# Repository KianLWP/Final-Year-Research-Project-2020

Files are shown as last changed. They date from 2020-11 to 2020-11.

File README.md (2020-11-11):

# Final-Year-Research-Project-2020
Repository for files and code used for my final year research project 2020: Inverted Pendulum Robot using IMU and Optical Flow as Feedback.    

A playlist with video demonstrations of the robot balancing can be found here:  
https://www.youtube.com/playlist?list=PL7QYRT00v9nzqrD0AZgUXMDRnrYgOC2eC

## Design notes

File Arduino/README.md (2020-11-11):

This directory contains the Arduino code used.    

The libraries used are Jeff Rowberg's MPU6050 library for Arduino, Pololu's VL53L1X library for Arduino and Bitcraze's Arduino driver for PMW3901 optical flow sensor.     
The links for their GitHubs are:      
https://github.com/jrowberg/i2cdevlib/tree/master/Arduino/MPU6050       
https://github.com/pololu/vl53l1x-arduino    
https://github.com/bitcraze/Bitcraze_PMW3901

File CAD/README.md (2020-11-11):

The CAD models for both the physical system and the electronic circuit can be found here.

Robot Assembly:

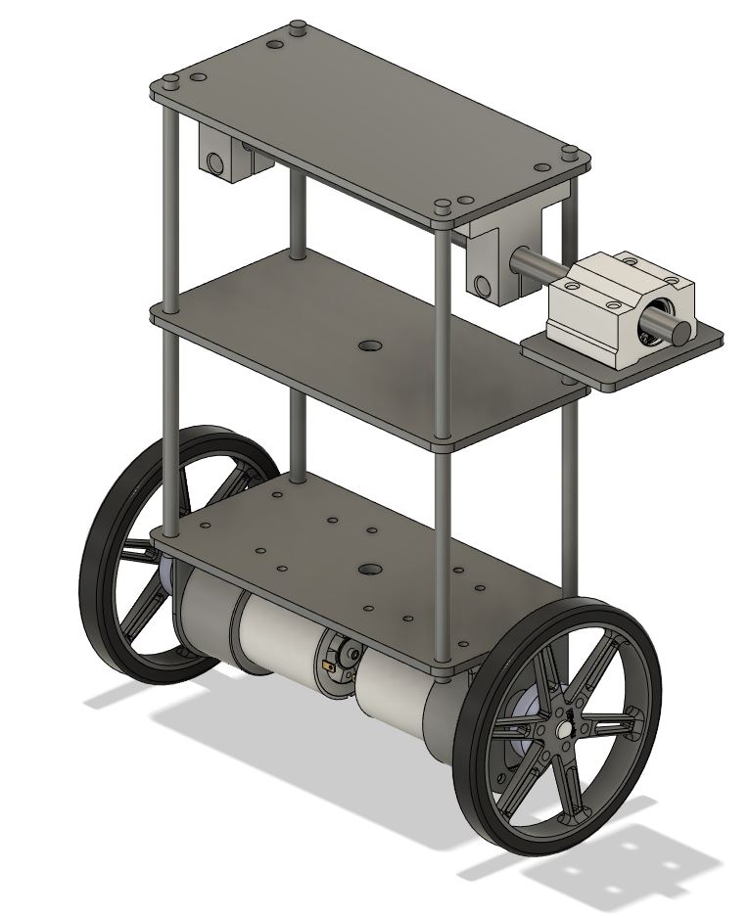
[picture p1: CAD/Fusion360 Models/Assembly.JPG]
Assembly


Circuit Design:

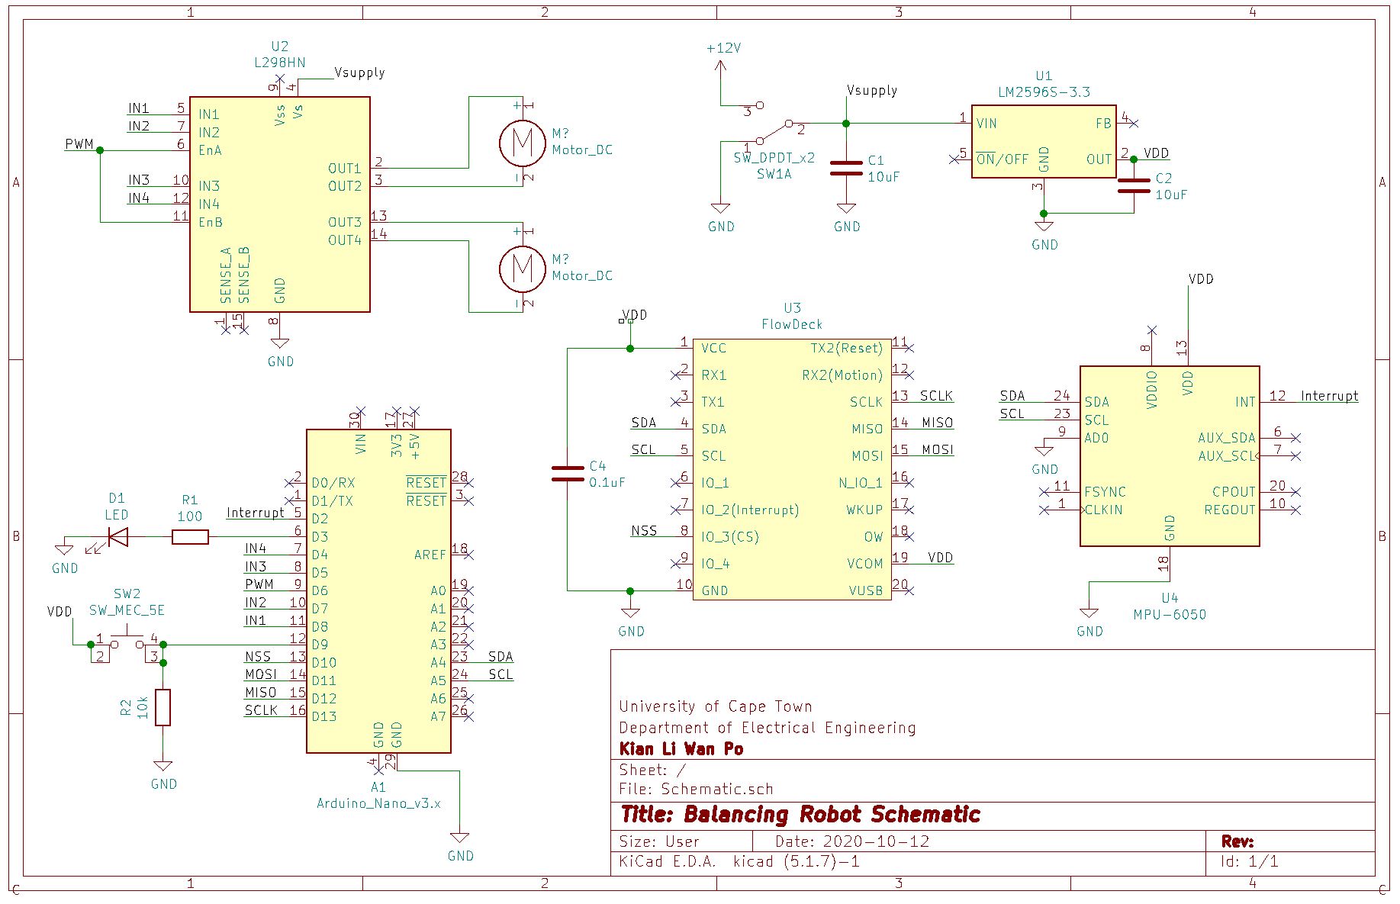
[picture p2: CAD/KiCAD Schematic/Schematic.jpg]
Schematic


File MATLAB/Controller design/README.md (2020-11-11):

Data and code when designing controllers for the two wheel balancing robot

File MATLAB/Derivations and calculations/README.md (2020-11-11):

Parameter calcualtion for the robot as well as a complete MATLAB live script for calculating the equations of motion, state-space model and calculating estimated required motor torque.   

The scripts used to calculated the linearized and unlinearized equations of motion are included.

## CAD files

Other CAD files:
CAD/Fusion360 Models/37 mm DC Geared Motor Mounting Bracket.f3d
CAD/Fusion360 Models/8mm rod.f3d
CAD/Fusion360 Models/Adjusted DC motor.f3d
CAD/Fusion360 Models/Gimballed Platform Assembly.f3z
CAD/Fusion360 Models/M5x160mm support rod.f3d
CAD/Fusion360 Models/Platform_ bottom.f3d
CAD/Fusion360 Models/Platform_ general.f3d
CAD/Fusion360 Models/Platform_ gimbal.f3d
CAD/Fusion360 Models/Platform_ middle.f3d
CAD/Fusion360 Models/Platform_ top.f3d
CAD/Fusion360 Models/Robot Assembly.f3z
CAD/Fusion360 Models/SCS8UU Block, Linear Bearing, 8mm Shaft.f3d
CAD/Fusion360 Models/Wheel Assembly.f3z
CAD/Fusion360 Models/pololu-universal-aluminum-mounting-hub-for-6mm-shaft-4-40-holes.f3d
CAD/Fusion360 Models/pololu-wheel-80x10mm-black.f3d
CAD/Fusion360 Models/sk8_rod_holder_v2.f3d

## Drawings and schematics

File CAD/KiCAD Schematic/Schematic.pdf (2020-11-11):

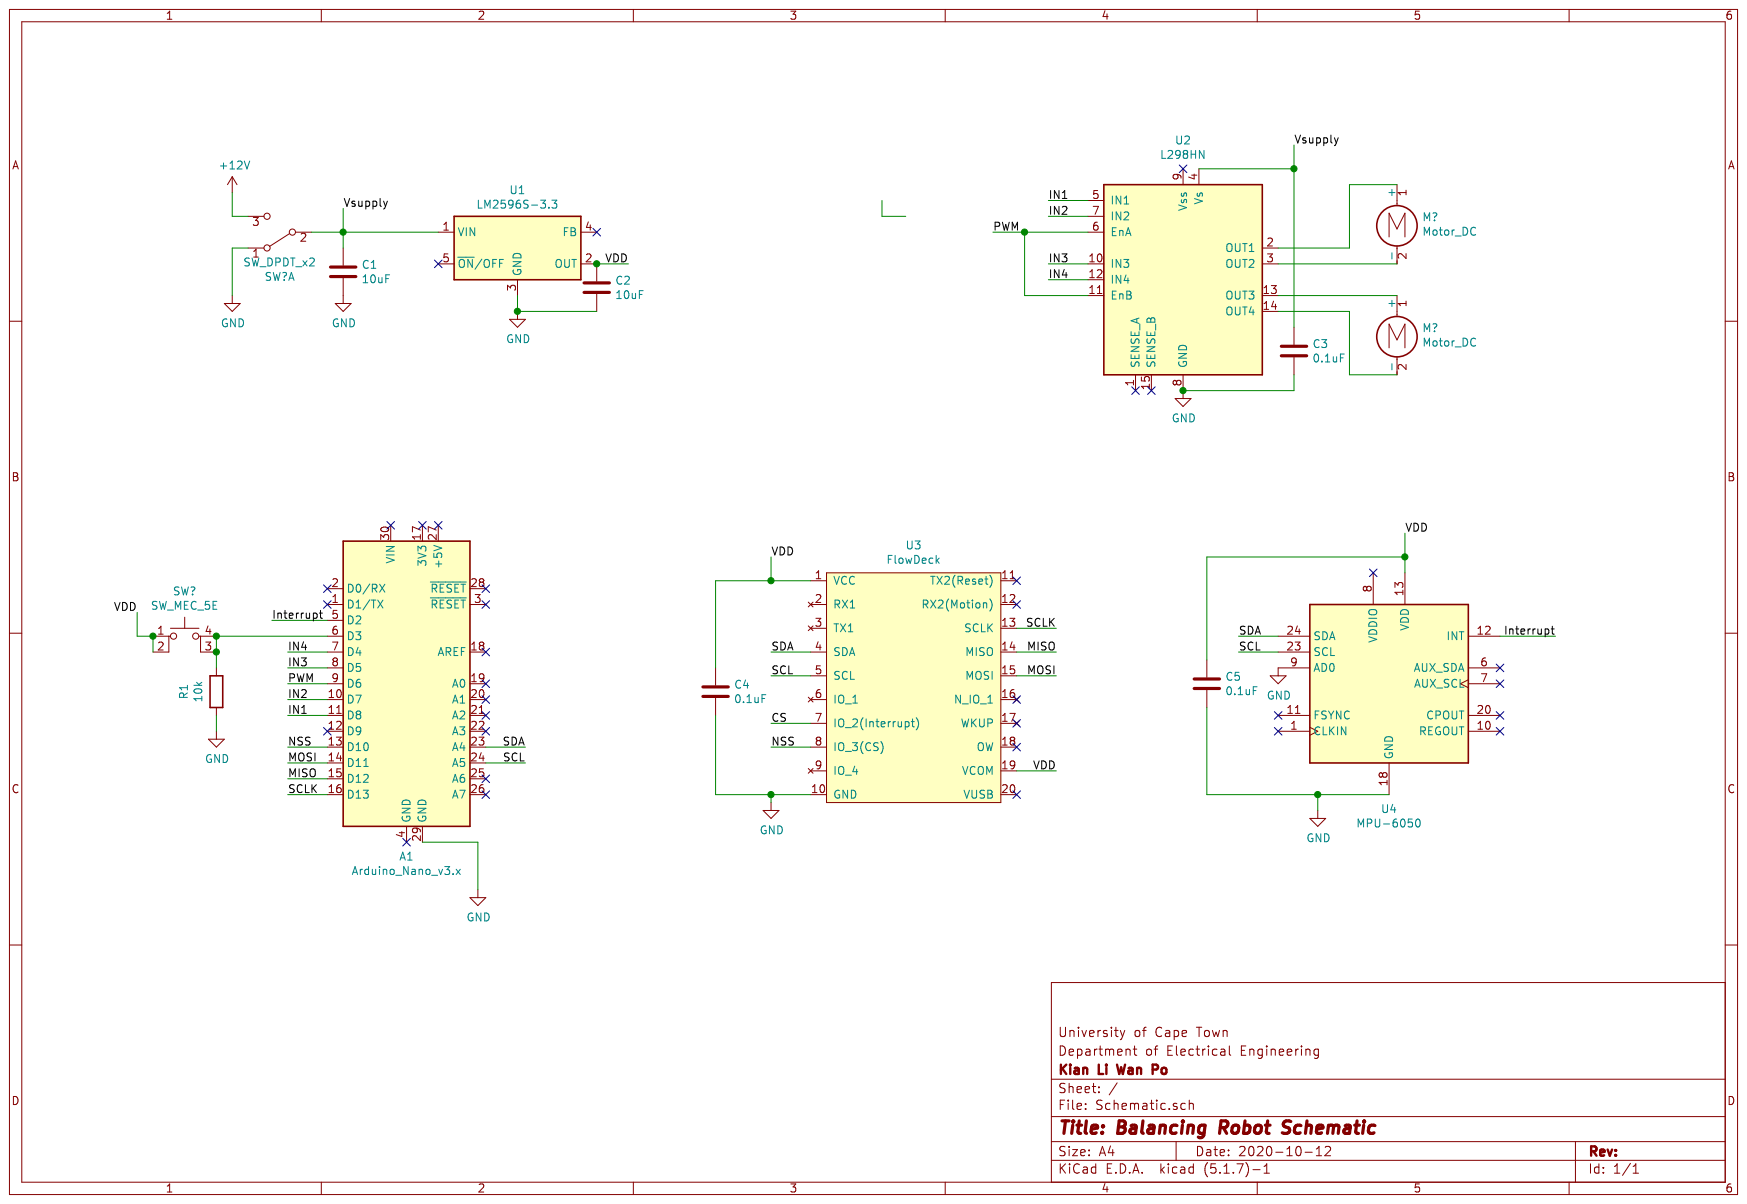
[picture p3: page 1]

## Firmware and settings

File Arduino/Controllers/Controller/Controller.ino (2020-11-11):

#include <Wire.h>
#include <VL53L1X.h>
#include "Bitcraze_PMW3901.h"
#include "MPU6050_6Axis_MotionApps20.h"


// ================================================================
// ===                        VARIABLES                         ===
// ================================================================

MPU6050 mpu;

//***************DMP VARIABLES*******************

// MPU control/status vars
bool dmpReady = false;  // set true if DMP init was successful
uint8_t mpuIntStatus;   // holds actual interrupt status byte from MPU
uint8_t devStatus;      // return status after each device operation (0 = success, !0 = error)
uint16_t packetSize;    // expected DMP packet size (default is 42 bytes)
uint16_t fifoCount;     // count of all bytes currently in FIFO
uint8_t fifoBuffer[64]; // FIFO storage buffer

// orientation/motion vars
Quaternion q;           // [w, x, y, z]         quaternion container
VectorFloat gravity;    // [x, y, z]            gravity vector
float euler[3];         // [psi, theta, phi]    Euler angle container
float ypr[3];           // [yaw, pitch, roll]   yaw/pitch/roll container and gravity vector

//***************VARIABLES*******************
// Program State
int ps = 0; //everytime push button is pressed or function is completed it is incremented
int btnPress = 0; 
//Loop variable
int c = 0;

//**************CONTROLLER GAINS******************

//float K1 = 0, K2 = 0, K3 = 0, K4 = 0;

//Ziegler Nichols
//Finding Ultimate gain and time
//float Kp = 150, Ki = 0, Kd = 0; //set gains to 0 and increase Kp until neutrally stable

//Ultimate Variables
float Ku = 150, Tu = 0.2168; //Found using Ziegler Nichols tuning method

      
//Gain Table

//Classic
// float Kp = Ku/2, Ki = 0, Kd = 0; //P
// float Kp = Ku/2.2, Ki = 1.2*Kp/Tu, Kd = 0; //PI
//float Kp = Ku*0.6, Ki = 2*Kp/Tu, Kd = Kp*Tu/8; //PID

//overshoot
//float Kp = 0.2*Ku;  //No overshoot
float Kp = 0.33*Ku; //Some overshoot
float Ki = 2*Kp/Tu, Kd = Kp*Tu/3; 

//Pessen Integral Rule
//float Kp = 0.7*Ku, Ki = 2.5*Kp/Tu, Kd = 0.15*Kp/Tu;


//old gains
//float Ku = 110, Tu = 0.22296; For gimbal //Original 70, 0.21964
//float Ku = 150, Tu = 0.5;
//float Ku = 100, Tu = 0.22694;

//
float errTot = 0, errPrev = 0;
//Time
unsigned long dt = 0, t0 = 0, t1 = 0; //time variable
//output  
const float v_min = 3.5;
const float v_max = 10.5;
float v_out;
int PWM_out;


//***************PINS**********************
#define INTERRUPT_PIN 2  // used for the DMP
#define LED 3   // LED pin
#define BTN 9 // switch button pin
//Left motor pins. 
//const int L_PWM = 9; 
#define L_IN1 8
#define L_IN2 7
//Right motor pins
#define R_PWM 6 //Using same PWM pin for consistency
#define R_IN1 5 
#define R_IN2 4

//**********PROGRAM SETTINGS**************
#define CALIBRATE_IMU;//comment to skip IMU calibration and use pre-calibrated offsets
//#define ZN_TUNING; //uncomment for Ziegler Nichols Tuning

void setup() {
  setupIMU();
  // Setup GPIO
  pinMode(LED, OUTPUT);
  pinMode(BTN, INPUT);

  //Motor setup
  pinMode(R_PWM, OUTPUT);
  pinMode(L_IN1, OUTPUT);
  pinMode(L_IN2, OUTPUT);
  pinMode(R_IN1, OUTPUT);
  pinMode(R_IN2, OUTPUT);

  Serial.println("Setup complete, awaiting user input");
  Serial.println("-----------------------------------");
  
  #ifdef ZN_TUNING
    Kp = 5;
    Ki = 0;
    Kd = 0;
    Serial.println("Ziegler Nichols Tuning");
  #endif

  Serial.print("Used gains: Kp=");
  Serial.print(Kp);
  Serial.print("  Ki=");
  Serial.print(Ki);
  Serial.print("  Kd=");
  Serial.println(Kd);
  Serial.println("-----------------------------------");
  
}

void loop() {
  ps = ps%5;  //ensures program state is from 0-3, including both 0 and 3
  switch (ps){
  case 1:
    initializeDMP();
    Serial.println("Ready to balance. Press button to start");
    Serial.println("---------------------------------------");
    ps++;
    break;
  case 2:
    c++;
    //do nothing, awaiting further user input
    digitalWrite(LED, (c/5000 % 2)); //blinks letting user know robot is ready
    break;
  case 3:
    if (mpu.dmpGetCurrentFIFOPacket(fifoBuffer)) { // Get the Latest packet 
      mpu.dmpGetQuaternion(&q, fifoBuffer);
      mpu.dmpGetGravity(&gravity, &q);
      mpu.dmpGetYawPitchRoll(ypr, &q, &gravity);
      v_out = PID_controller(ypr[1]); //angle in rads
      motorVoltage(v_out); //send voltage to motors
      
      //Log angle and sample time
      Serial.print(ypr[1],4); 
      Serial.print("\t");
      Serial.println(dt);  
    } 
    break;
  case 4:
    #ifdef ZN_TUNING
      Kp = Kp + 5;
      Serial.print("Increasing Kp: ");
      Serial.println(Kp);
    #endif
    ps++;
    break;
  default:
    motorStop();
    break;
  }  
  btnPress = digitalRead(BTN);  // Reading button status / input
  if (btnPress == HIGH)  // Condition to check button input
  {
    Serial.println("Button Press");
    ps++;
    delay(1000); //debounce time and delay
    if (ps == 3)
    {
      digitalWrite(LED,1);
      // ensure variables are reset for controller
      errTot = 0;
      errPrev = 0;
      t1 = micros(); 
    }
  }
}


// ================================================================
// ===                   CONTROLLER FUNCTION                    ===
// ================================================================
float PID_controller(float err) { 
  //input is error, desired angle-current angle
  float result;
  //time
  t0 = t1;
  t1 = micros();
  dt = (t1-t0); //in ms
  //Controller output
  //Kp[e(t)] + Ki[integral(e(t).dt)] + Kd[e(t).d/dt]
  errTot = errTot+err;
  result = Kp*err + Ki*errTot*dt/1000000 + Kd*(err-errPrev)*1000000/dt; 
  errPrev = err;
  return result;
}

// ================================================================
// ===                      MOTOR FUNCTION                      ===
// ================================================================
void motorVoltage(float v) {
  if (v>0) {
    motorDirection(false);
  }
  else if (v<0) {
    motorDirection(true);
    v = v*-1; //only +ve PWM signals are sent out
    Serial.print("-"); //print sign of voltage, used for voltage logging
  }
  v = constrain(v, v_min, v_max); //prevent voltage from going out of bounds
  Serial.print(v);
  Serial.print("\t");
  motorPWM(v); //convert to PWM
}

void motorDirection(bool dir) { //0 +ve, 1 -ve direction
  if (dir) {
    digitalWrite(L_IN1, 1);
    digitalWrite(L_IN2, 0);
    digitalWrite(R_IN1, 1);
    digitalWrite(R_IN2, 0);
  } else {
    digitalWrite(L_IN1, 0);
    digitalWrite(L_IN2, 1);
    digitalWrite(R_IN1, 0);
    digitalWrite(R_IN2, 1);
  }
}

void motorStop() {
  digitalWrite(L_IN1, 1);
  digitalWrite(L_IN2, 1);
  digitalWrite(R_IN1, 1);
  digitalWrite(R_IN2, 1);
}

void motorPWM(float v) {
  PWM_out = round(v*255/v_max);  //maps voltage to appropriate PWM duty cycle, motor driver will convert into appropriate voltage. 
                              //Can use map function; however, it supresses fractions inside the function
  analogWrite(R_PWM, PWM_out);   
}
// ================================================================
// ===                      IMU FUNCTIONS                       ===
// ================================================================
// Code in this section was taken and adapted from Jeff Rowbergs MPU6050 I2Clibrary for Arduino. The example used as reference is cited
/***************************************************************************************
*    Title: MPU6050_DMP6.ino
*    Author: Jeff Rowberg
*    Date: 2019
*    Code version: 2.0
*    Availability: https://github.com/jrowberg/i2cdevlib/tree/master/Arduino/MPU6050/examples/MPU6050_DMP6
*   
***************************************************************************************/
// Code in this section was taken and adapted from Jeff Rowbergs MPU6050 I2Clibrary for Arduino. The example used as reference is
void setupIMU(){
  // join I2C bus (I2Cdev library doesn't do this automatically)
  #if I2CDEV_IMPLEMENTATION == I2CDEV_ARDUINO_WIRE
      Wire.begin();
      Wire.setClock(400000); // 400kHz I2C clock. Comment this line if having compilation difficulties
  #elif I2CDEV_IMPLEMENTATION == I2CDEV_BUILTIN_FASTWIRE
      Fastwire::setup(400, true);
  #endif
  
  Serial.begin(115200);
  while (!Serial); // wait for Leonardo enumeration, others continue immediately

  // initialize device
  Serial.println(F("Initializing I2C devices..."));
  mpu.initialize();
  pinMode(INTERRUPT_PIN, INPUT);
  // verify connection
  Serial.println(F("Testing device connections..."));
  Serial.println(mpu.testConnection() ? F("MPU6050 connection successful") : F("MPU6050 connection failed"));
}

void initializeDMP() {
  digitalWrite(LED, HIGH);
  // load and configure the DMP
  Serial.println(F("Initializing DMP..."));
  devStatus = mpu.dmpInitialize();
  
//OFFSETS    -4076,    -635,    1448,    -709,      44,     -34
  mpu.setXAccelOffset(-4076);
  mpu.setYAccelOffset(-635);
  mpu.setZAccelOffset(1448); 
  mpu.setXGyroOffset(-709);
  mpu.setYGyroOffset(44);
  mpu.setZGyroOffset(-34);
  // make sure it worked (returns 0 if so)
  if (devStatus == 0) {
    #ifdef CALIBRATE_IMU
      // Calibration Time: generate offsets and calibrate our MPU6050
      mpu.CalibrateAccel(6);
      mpu.CalibrateGyro(6);
      mpu.PrintActiveOffsets();
    #endif
    
    // turn on the DMP, now that it's ready
    Serial.println(F("Enabling DMP..."));
    mpu.setDMPEnabled(true);

    // enable Arduino interrupt detection
    Serial.print(F("Enabling interrupt detection (Arduino external interrupt "));
    Serial.print(digitalPinToInterrupt(INTERRUPT_PIN));
    Serial.println(F(")..."));
    attachInterrupt(digitalPinToInterrupt(INTERRUPT_PIN), dmpDataReady, RISING);
    mpuIntStatus = mpu.getIntStatus();

    // set our DMP Ready flag so the main loop() function knows it's okay to use it
    Serial.println(F("DMP ready"));
    dmpReady = true;

    // get expected DMP packet size for later comparison
    packetSize = mpu.dmpGetFIFOPacketSize();
  } else {
    // ERROR!
    // 1 = initial memory load failed
    // 2 = DMP configuration updates failed
    // (if it's going to break, usually the code will be 1)
    Serial.print(F("DMP Initialization failed (code "));
    Serial.print(devStatus);
    Serial.println(F(")"));
  }
  digitalWrite(LED, LOW);
}

//Interruption Detection

volatile bool mpuInterrupt = false;     // indicates whether MPU interrupt pin has gone high
void dmpDataReady() {
  mpuInterrupt = true;
}

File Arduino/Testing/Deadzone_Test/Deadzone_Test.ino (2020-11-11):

#include <Wire.h>
#include <math.h>

//***************VARIABLES*******************
// Program State
int ps = 0; //everytime push button is pressed or function is completed it is incremented
int btnPress = 0; 

//output
float v_out;
const float v_max = 10.5;
int PWM_out;
//***************PINS**********************
const int BTN = 9; // Naming switch button pin
const int LED = 3;   // Namin LED pin
//Left motor pins.  
const int L_IN1 = 8;
const int L_IN2 = 7;
//Right motor pins
const int PWM = 6;
const int R_IN1 = 5; 
const int R_IN2 = 4;

void setup() {
  Serial.begin(115200);
  Wire.setClock(400000);
  Wire.begin();
  delay(250);
  // Setup GPIO
  pinMode(LED, OUTPUT);
  pinMode (BTN, INPUT);

  //Motor setup
  pinMode(PWM, OUTPUT);
  pinMode(L_IN1, OUTPUT);
  pinMode(L_IN2, OUTPUT);
  pinMode(R_IN1, OUTPUT);
  pinMode(R_IN2, OUTPUT);

//  motorStop();
  v_out= 2;
  motorDirection(true);
  motorPWM(v_out);
  Serial.print("V_out: ");
  Serial.print(v_out);
  Serial.print("  PWM: ");
  Serial.println(PWM_out);
}

void loop() {
  btnPress = digitalRead(BTN);  // Reading button status / input
  if (btnPress == HIGH)  // Condition to check button input
  {
    v_out = v_out+.25;
    motorPWM(v_out);
    Serial.print("V_out: ");
    Serial.print(v_out);
    Serial.print("  PWM: ");
    Serial.println(PWM_out);
    delay(1000);
  }
}


void motorDirection(bool dir) { //0 +ve, 1 -ve direction
  if (dir) {
    digitalWrite(L_IN1, 0);
    digitalWrite(L_IN2, 1);
    digitalWrite(R_IN1, 0);
    digitalWrite(R_IN2, 1);
  } else {
    digitalWrite(L_IN1, 1);
    digitalWrite(L_IN2, 0);
    digitalWrite(R_IN1, 1);
    digitalWrite(R_IN2, 0);
  }

}

void motorStop() {
  digitalWrite(L_IN1, 1);
  digitalWrite(L_IN2, 1);
  digitalWrite(R_IN1, 1);
  digitalWrite(R_IN2, 1);
}

void motorPWM(float v) {
  PWM_out = round(v*255/v_max);  //coverts controller v_out to appropriate PWM duty cycle, motor driver will convert into appropriate voltage.
                              //+0.5 ensures it always rounds to the nearest whole PWM, int truncates 
                             //Can use map function; however, it supresses fractions inside the function
  analogWrite(PWM, PWM_out);
}
